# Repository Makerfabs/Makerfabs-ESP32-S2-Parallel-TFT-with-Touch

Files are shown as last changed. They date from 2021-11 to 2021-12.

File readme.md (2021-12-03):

# Makerfabs ESP32-S2 Parallel TFT with Touch

```c++
/*
Version:		V1.0
Author:			Vincent
Create Date:	2021/11/22
Note:
	
*/
```
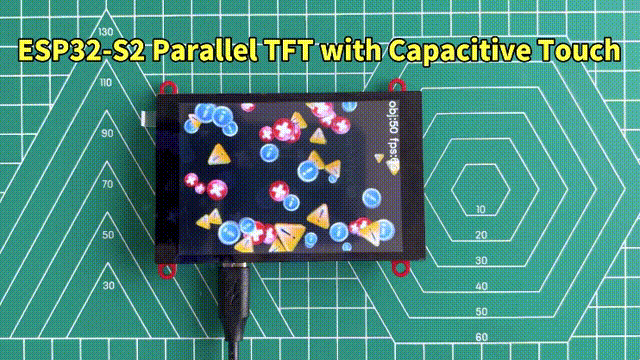
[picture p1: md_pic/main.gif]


[toc]

# Makerfabs

[Makerfabs home page](https://www.makerfabs.com/)

[Makerfabs Wiki](https://makerfabs.com/wiki/index.php?title=Main_Page)

# Makerfabs ESP32-S2 Parallel TFT with Touch
## Intruduce

Product Link ：[esp32-s2-parallel-tft-with-touch-3-5-ili9488](https://www.makerfabs.com/esp32-s2-parallel-tft-with-touch-3-5-ili9488.html) 

Wiki Link : [ESP32-S2 Parallel TFT with Touch(3.5'')](https://www.makerfabs.com/wiki/index.php?title=ESP32-S2_Parallel_TFT_with_Touch(3.5%27%27)) 

The 3.5" 320x480 TFT LCD driver is ILI9488, it uses 16bits parallel line for communication with ESP32-S2, the main clock could be up to 20MHz, make the display smooth enough for videos; You can freely use some of Mabee pins(A I2c and a IOs) with the breakout connectors, to connect the ESP32-S2 display with sensors/ actuators, suitable for IoT applications.

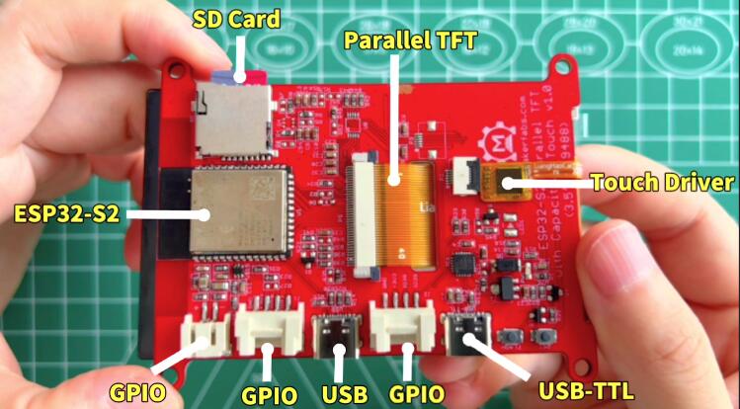
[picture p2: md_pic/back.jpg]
back


## Feature

- Integrated ESP32-S2 with 2.4G WiFi
- Wi-Fi Protocols: 802.11b/g/n(802.11n up to 150Mbps),A-MPDU and A-MSDU aggregation and 0.4us guard interval support
- Wi-Fi Frequency range: 2.402GHz - 2.483Ghz
- Arduino Compatible: You can play it with Arduino IDE
- LCD 3.5 inch Amorphous-TFT-LCD (Thin Film Transistor Liquid Crystal Display) for mobile-phone or handy electrical equipment
- LCD Driver: ILI9488(16bits parallel line)
- LCD Resolution: 320*480
- FT6236 Series ICs are single-chip capacitive touch panel controller IC with a built-in 16 bit enhanced Micro-controller unit (MCU)
- NS2009: A 4-wire resistive touch screen control circuit with I2C interface, which contains A 12-bit resolution A/D converter
- Power supply: 5V, Type-C USB
- Micro SD card slot on the board
- Dual USB Type-C: one for native USB and one for USB-to-UART
- Two Mabee interfaces
- Board size: 66mm * 85mm

# Code Explain

## Complier Option

- Install board : ESP32 .
- Install library : LovyanGFX library. 
- Edit the code based on the touch screen. If you use resistive screen, choice NS2009_TOUCH. If you use capacitive screen, choice FT6236_TOUCH. 
- Use type-c use cable connect USB-TTL to PC.
- Upload codes, select "ESP32-S2 DEV Module" and "UART0"

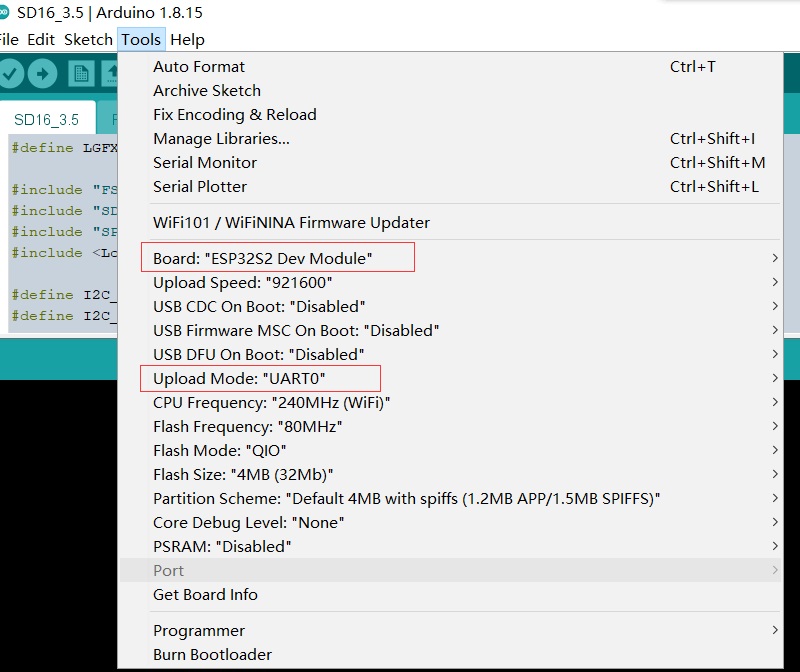
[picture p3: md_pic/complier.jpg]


## Firmware

### SD16_3.5

Factory firmware. First run the boot self-test to check the hardware. Press down the middle of the touch screen as prompted to display a LOGO picture on the SD card. Finally, print the touch coordinates in the serial port.

## Example

### Simple Test

Three frame rate tests and SD card read and write tests.

- FillScreen

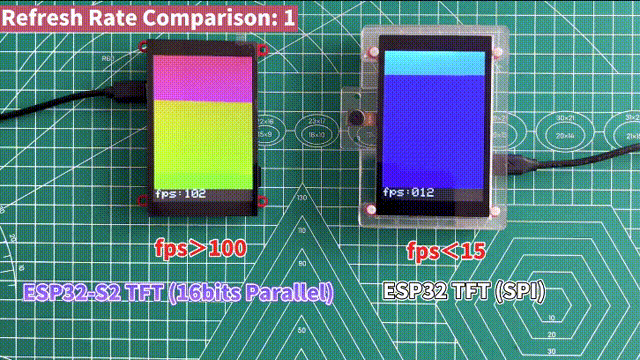
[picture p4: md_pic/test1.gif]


- Graph

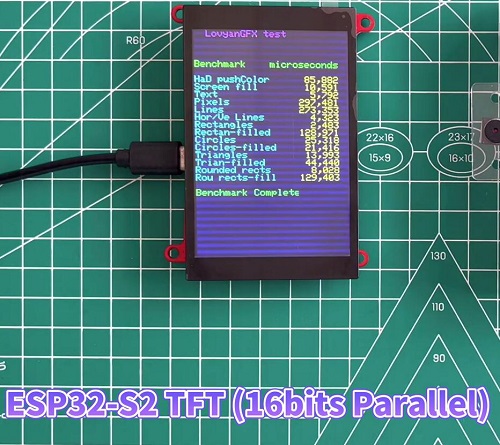
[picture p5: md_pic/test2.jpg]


- Touch

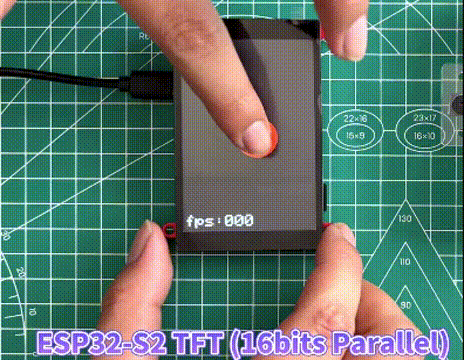
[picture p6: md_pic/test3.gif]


- PWM_backlight

Use pwm control screen back light.

### Display Demo

The display of 5 display effects is modified from Lovyan's example. There are also two homemade demonstration videos: ultrasonic ranging and line charts.

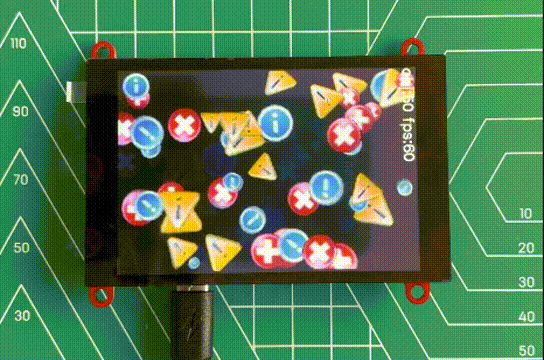
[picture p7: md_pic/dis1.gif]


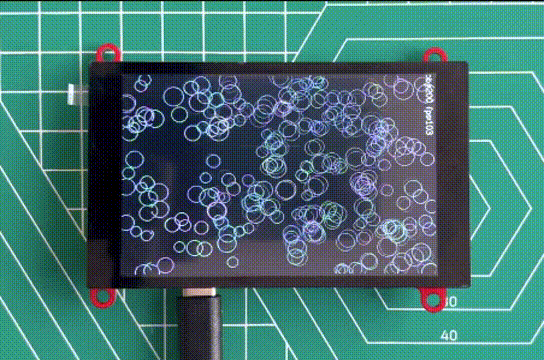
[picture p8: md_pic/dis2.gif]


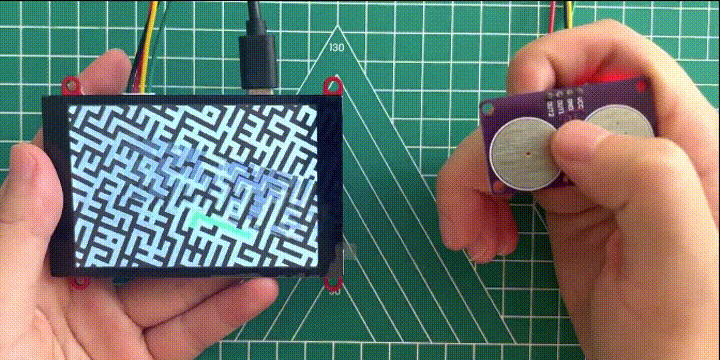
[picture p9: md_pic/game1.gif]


### Wifi Img

Receive TXT and BMP files over WIFI and display them on the screen.

Added a WiFi bulletin board app. You can upload and browse files in the SD card through the web page. And the latest uploaded BMP or TXT display on the 3.5-inch screen.

- Library Install：[esp32-micro-sdcard](https://github.com/nhatuan84/esp32-micro-sdcard) and [esp32-webserver](https://github.com/nhatuan84/esp32-webserver)
- Upload .\example\wifi_img_16\wifi_img_16.ino
- Insert the SD card and power on.
- Enter the IP address on the screen in your browser.

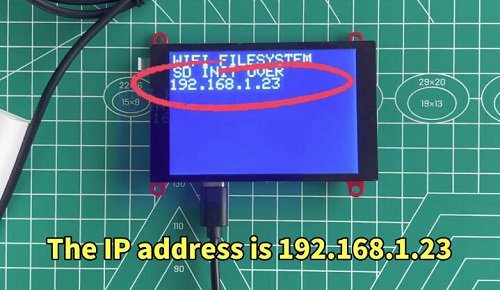
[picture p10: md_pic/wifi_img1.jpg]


- Select TXT or BMP to be uploaded. BMP must be 480 x 320 pixels, 24 bits.

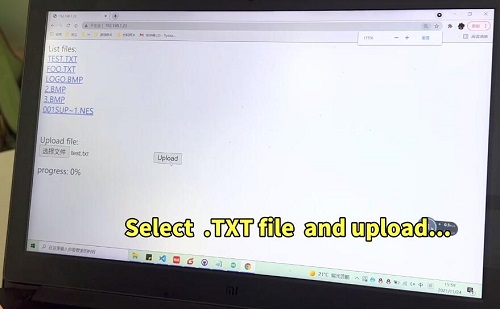
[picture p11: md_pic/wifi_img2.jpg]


- Upload.
- Wait seconds, the content is displayed on the screen.

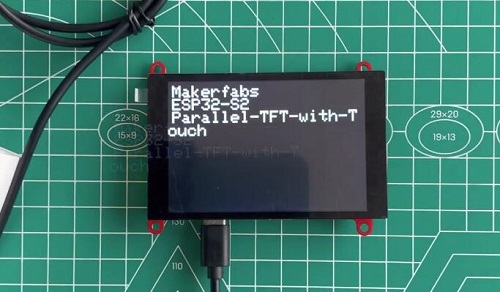
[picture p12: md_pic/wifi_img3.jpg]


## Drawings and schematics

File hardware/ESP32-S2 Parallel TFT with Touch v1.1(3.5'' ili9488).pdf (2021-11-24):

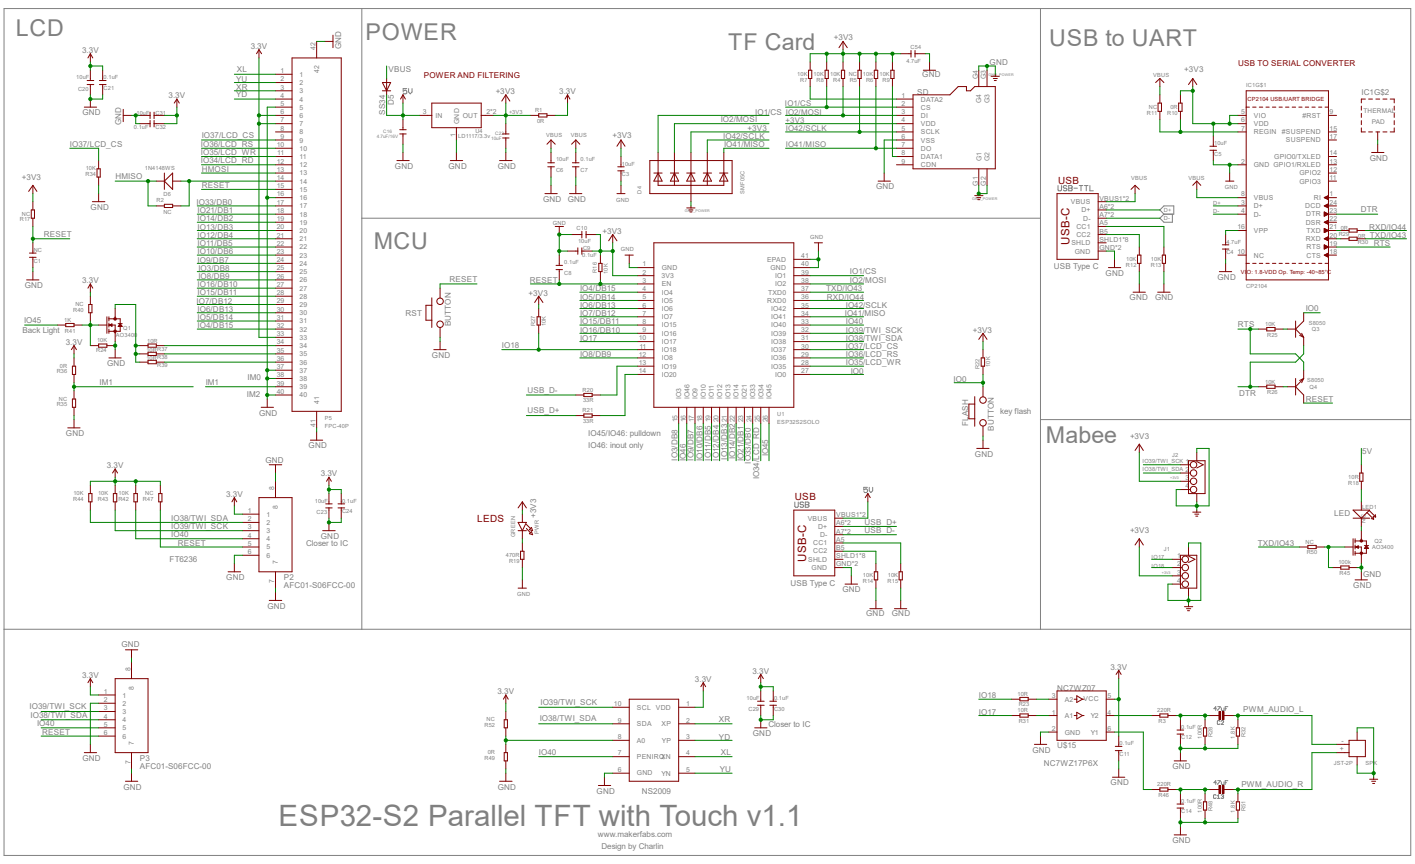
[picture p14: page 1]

USB TO SERIAL CONVERTER

VIO: 1.8-VDD Op. Temp: -40~85°C USB⁻C USB⁻C

IO39/TWI_SCK 3
IO40 4

ESP32-S2 Parallel TFT with Touch v1.1

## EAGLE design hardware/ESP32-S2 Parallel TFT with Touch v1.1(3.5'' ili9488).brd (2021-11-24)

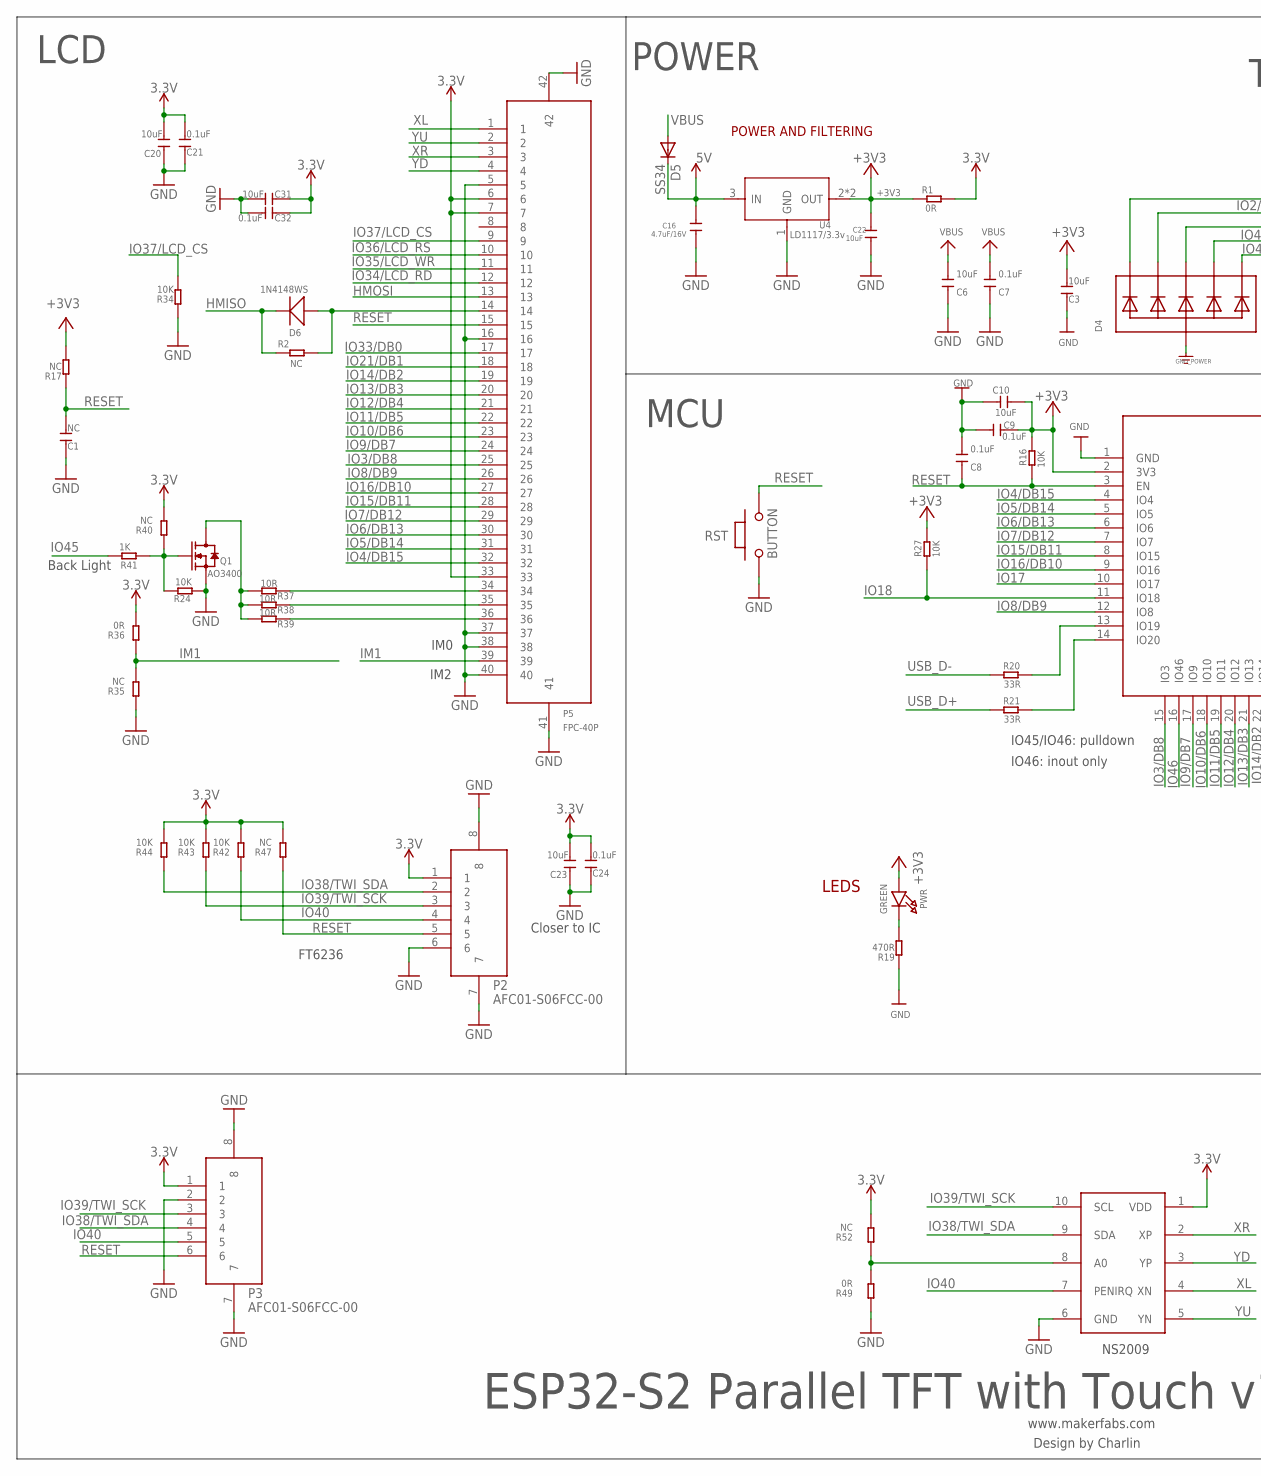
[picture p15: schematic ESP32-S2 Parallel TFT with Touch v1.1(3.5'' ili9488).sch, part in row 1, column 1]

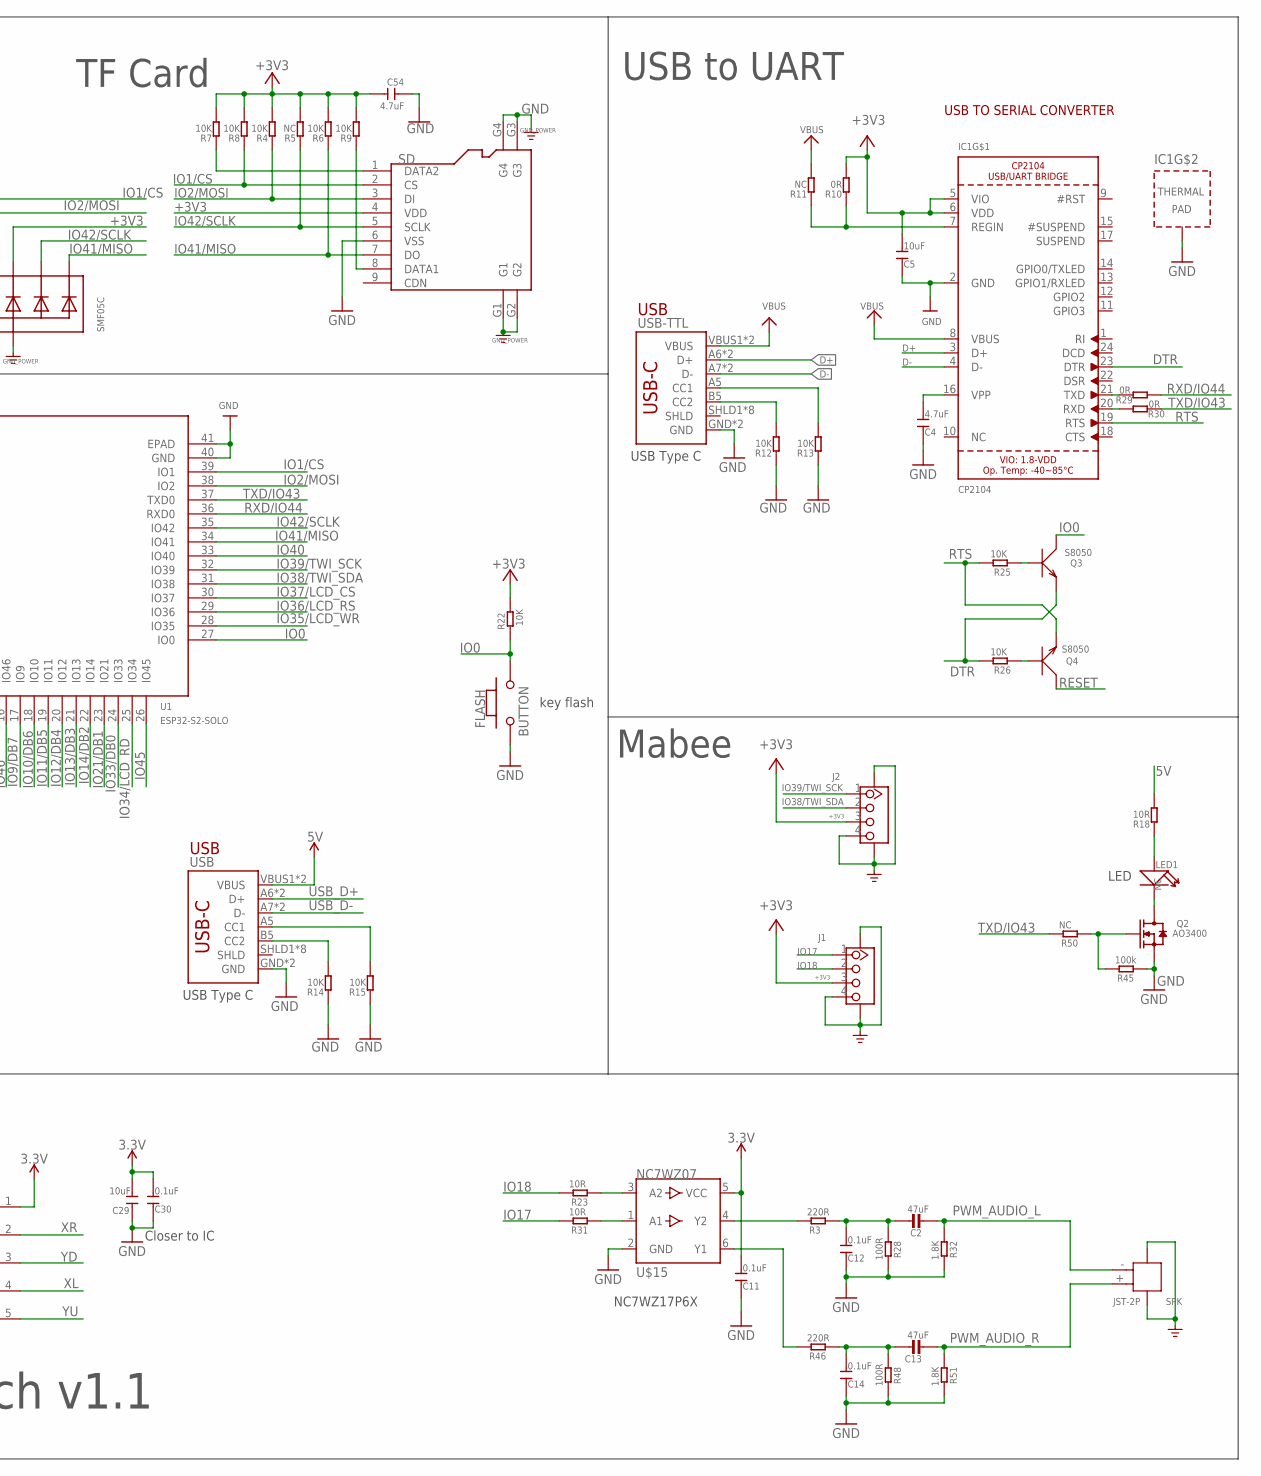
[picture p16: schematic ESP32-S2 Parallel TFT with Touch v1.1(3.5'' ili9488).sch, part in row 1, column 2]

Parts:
C1: NC; DISCRETE_C0603
C2, C13: 47uF; MICROBUILDER_0805
C3, C5, C6, C10, C20, C23, C29, C31: 10uF; DISCRETE_C0603
C4, C54: 4.7uF; DISCRETE_C0603
C7, C8, C9, C11, C12, C14, C21, C24, C30, C32: 0.1uF; DISCRETE_C0603
C16: 4.7uF/16V; 0603
C22: 10uF; 0603
D4: SMF05C; SOT363
D5: SS34; DO-214AC
D6: 1N4148WS; SOD323
FLASH: BUTTON; 157SW
IC1: CP2104; QFN24_4MM_SMSC
J1, J2: GROVE-CONNECTOR-SMD'90D'; HW4-SMD-2.0-90D
LED1: NC; DISCRETE_LED-3528
P2, P3: AFC01-S06FCC-00; SMD8-50P-740L535W
P5: FPC-40P; SMD42-50P-2560L490W
PWR: GREEN; CHIPLED_0805_NOOUTLINE
Q1, Q2: AO3400; SOT23@1
Q3, Q4: S8050; SOT23
R1, R29, R30: 0R; R0603
R2, R50: NC; R0603
R3, R46: 220R; R0603
R4, R6, R7, R8, R9, R12, R13, R14, R15, R24, R34, R42, R43, R44: 10K; DISCRETE_R0603
R5, R11, R17, R35, R40, R47, R52: NC; DISCRETE_R0603
R10, R36, R49: 0R; DISCRETE_R0603
R16, R22, R25, R26, R27: 10K; R0603
R18, R37, R38, R39: 10R; DISCRETE_R0603
R19: 470R; DISCRETE_R0603
R20, R21: 33R; R0603
R23, R31: 10R; R0603
R28, R48: 100R; R0603
R32, R51: 1.8K; R0603
R41: 1K; DISCRETE_R0603
R45: 100k; R0603
RST: BUTTON; 157SW
SD: HOLDER-MICROSD-9P; 9P-SMD-W/-RING
SPK: JST-2P; HW2-SMD-2.0-90D
U1: ESP32­S2­SOLO; ESP32-­S2-­SOLO
U4: LD1117/3.3v; SOT89
U8: NS2009; MSOP10
U$15: NC7WZ07; SC70-6
USB: USB_C5; USB-C-16P-5
USB-TTL: USB_C5; USB-C-16P-5

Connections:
3.3V: C11.2, C20.2, C21.2, C23.2, C24.2, C29.2, C30.2, C31.1, C32.1, P2.1, P3.1, P5.6, P5.7, P5.33, R1.2, R36.2, R40.2, R42.2, R43.2, R44.2, R47.2, R52.2, U8.1 (VDD), U$15.5 (VCC)
5V: C16.1, D5.C, R18.2, U4.3 (IN), USB.VBUS1 (VBUS), USB.VBUS2 (VBUS)
+3V3: C3.2, C5.2, C9.1, C10.1, C22.1, C54.2, D4.4 (C3), IC1.5 (VIO), IC1.6 (VDD), J1.3, J2.3, PWR.A, R1.1, R4.2, R5.2, R6.2, R7.2, R8.2, R9.2, R10.2, R16.2, R17.2, R22.2, R27.2, SD.4 (VDD), U1.2 (3V3), U4.2 (OUT), U4.4 (OUT)
D+: IC1.3 (D+), USB-TTL.A6 (D+), USB-TTL.B6 (D+)
D-: IC1.4 (D-), USB-TTL.A7 (D-), USB-TTL.B7 (D-)
DTR: IC1.23 (DTR), Q3.2 (E), R26.2
GND: C1.1, C3.1, C4.1, C5.1, C6.1, C7.1, C8.2, C9.2, C10.2, C11.1, C12.1, C14.1, C16.2, C20.1, C21.1, C22.2, C23.1, C24.1, C29.1, C30.1, C31.2, C32.2, C54.1, D4.2 (A), FLASH.1, IC1.2 (GND), IC1.THERM (TP), J1.4, J1.SS1, J1.SS2, J2.4, J2.SS1, J2.SS2, P2.6, P2.7, P2.8, P3.2, P3.7, P3.8, P5.5, P5.16, P5.37, P5.38, P5.40, P5.41, P5.42, Q1.2 (S), Q2.2 (S), R12.1, R13.1, R14.1, R15.1, R19.1, R24.1, R28.2, R32.2, R34.1, R35.1, R45.1, R48.2, R49.1, R51.2, RST.1, SD.6 (VSS), SD.G1, SD.G2, SD.G3, SD.G4, SPK.3, SPK.4, U1.1 (GND), U1.40 (GND), U1.41 (EPAD), U4.1 (GND), U8.6 (GND), U$15.2 (GND), USB.GND, USB.GND2 (GND), USB-TTL.GND, USB-TTL.GND2 (GND)
HMISO: D6.-, R2.1
HMOSI: P5.13
IM1: P5.39, R35.2, R36.1
IO0: FLASH.2, Q3.3 (C), R22.1, U1.27 (IO0)
IO1/CS: D4.1 (C1), R8.1, SD.2 (CS), U1.39 (IO1)
IO2/MOSI: D4.3 (C2), R4.1, SD.3 (DI), U1.38 (IO2)
IO3/DB8: P5.25, U1.15 (IO3)
IO4/DB15: P5.32, U1.4 (IO4)
IO5/DB14: P5.31, U1.5 (IO5)
IO6/DB13: P5.30, U1.6 (IO6)
IO7/DB12: P5.29, U1.7 (IO7)
IO8/DB9: P5.26, U1.12 (IO8)
IO9/DB7: P5.24, U1.17 (IO9)
IO10/DB6: P5.23, U1.18 (IO10)
IO11/DB5: P5.22, U1.19 (IO11)
IO12/DB4: P5.21, U1.20 (IO12)
IO13/DB3: P5.20, U1.21 (IO13)
IO14/DB2: P5.19, U1.22 (IO14)
IO15/DB11: P5.28, U1.8 (IO15)
IO16/DB10: P5.27, U1.9 (IO16)
IO17: J1.1, R31.2, U1.10 (IO17)
IO18: J1.2, R23.2, R27.1, U1.11 (IO18)
IO21/DB1: P5.18, U1.23 (IO21)
IO33/DB0: P5.17, U1.24 (IO33)
IO34/LCD_RD: P5.12, U1.25 (IO34)
IO35/LCD_WR: P5.11, U1.28 (IO35)
IO36/LCD_RS: P5.10, U1.29 (IO36)
IO37/LCD_CS: P5.9, R34.2, U1.30 (IO37)
IO38/TWI_SDA: J2.2, P2.2, P3.4, R44.1, U1.31 (IO38), U8.9 (SDA)
IO39/TWI_SCK: J2.1, P2.3, P3.3, R43.1, U1.32 (IO39), U8.10 (SCL)
IO40: P2.4, P3.5, R42.1, U1.33 (IO40), U8.7 (PENIRQ)
IO41/MISO: D4.6 (C5), R6.1, SD.7 (DO), U1.34 (IO41)
IO42/SCLK: D4.5 (C4), R5.1, SD.5 (SCLK), U1.35 (IO42)
IO45: R41.2, U1.26 (IO45)
IO46: U1.16 (IO46)
unnamed: C4.2, IC1.16 (VPP)
unnamed: Q4.1 (B), R26.1
unnamed: Q3.1 (B), R25.1
unnamed: D6.+, P5.14, R2.2
unnamed: Q2.1 (G), R45.2, R50.1
unnamed: R15.2, USB.A5 (CC1)
unnamed: PWR.C, R19.2
unnamed: LED1.1 (+), R18.1
unnamed: LED1.2 (-), Q2.3 (D)
unnamed: R13.2, USB-TTL.A5 (CC1)
unnamed: R12.2, USB-TTL.B5 (CC2)
unnamed: IC1.7 (REGIN), R10.1, R11.1
unnamed: R3.2, U$15.4 (Y2)
unnamed: R14.2, USB.B5 (CC2)
unnamed: R20.2, U1.13 (IO19)
unnamed: R21.2, U1.14 (IO20)
unnamed: C2.1, C12.2, R3.1, R28.1
unnamed: IC1.21 (TXD), R29.2
unnamed: IC1.20 (RXD), R30.2
unnamed: P5.34, R37.1
unnamed: P5.35, R38.1
unnamed: P5.36, R39.1
unnamed: Q1.1 (G), R24.2, R40.1, R41.1
unnamed: Q1.3 (D), R37.2, R38.2, R39.2
unnamed: R49.2, R52.1, U8.8 (A0)
unnamed: R46.2, U$15.6 (Y1)
unnamed: R23.1, U$15.3 (A2)
unnamed: R31.1, U$15.1 (A1)
unnamed: C13.1, C14.2, R46.1, R48.1
unnamed: R7.1, SD.1 (DATA2)
unnamed: R9.1, SD.8 (DATA1)
PWM_AUDIO_L: C2.2, R32.1, SPK.- (2)
PWM_AUDIO_R: C13.2, R51.1, SPK.+ (1)
RESET: C1.2, C8.1, P2.5, P3.6, P5.15, Q4.3 (C), R16.1, R17.1, R47.1, RST.2, U1.3 (EN)
RTS: IC1.19 (RTS), Q4.2 (E), R25.2
RXD/IO44: R29.1, U1.36 (RXD0)
TXD/IO43: R30.1, R50.2, U1.37 (TXD0)
USB_D+: R21.1, USB.A6 (D+), USB.B6 (D+)
USB_D-: R20.1, USB.A7 (D-), USB.B7 (D-)
VBUS: C6.2, C7.2, D5.A, IC1.8 (VBUS), R11.2, USB-TTL.VBUS1 (VBUS), USB-TTL.VBUS2 (VBUS)
XL: P5.1, U8.4 (XN)
XR: P5.3, U8.2 (XP)
YD: P5.4, U8.3 (YP)
YU: P5.2, U8.5 (YN)

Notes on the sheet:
www.makerfabs.com
Design by Charlin
USB
LEDS
POWER AND FILTERING
USB TO SERIAL CONVERTER
key flash
ESP32-S2 Parallel TFT with Touch v1.1
POWER
USB to UART
USB Type C
TF Card
LED
NS2009
FT6236
Closer to IC
Back Light
IM0
IM2
IO45/IO46: pulldown
IO46: inout only
NC7WZ17P6X
Mabee
LCD
MCU

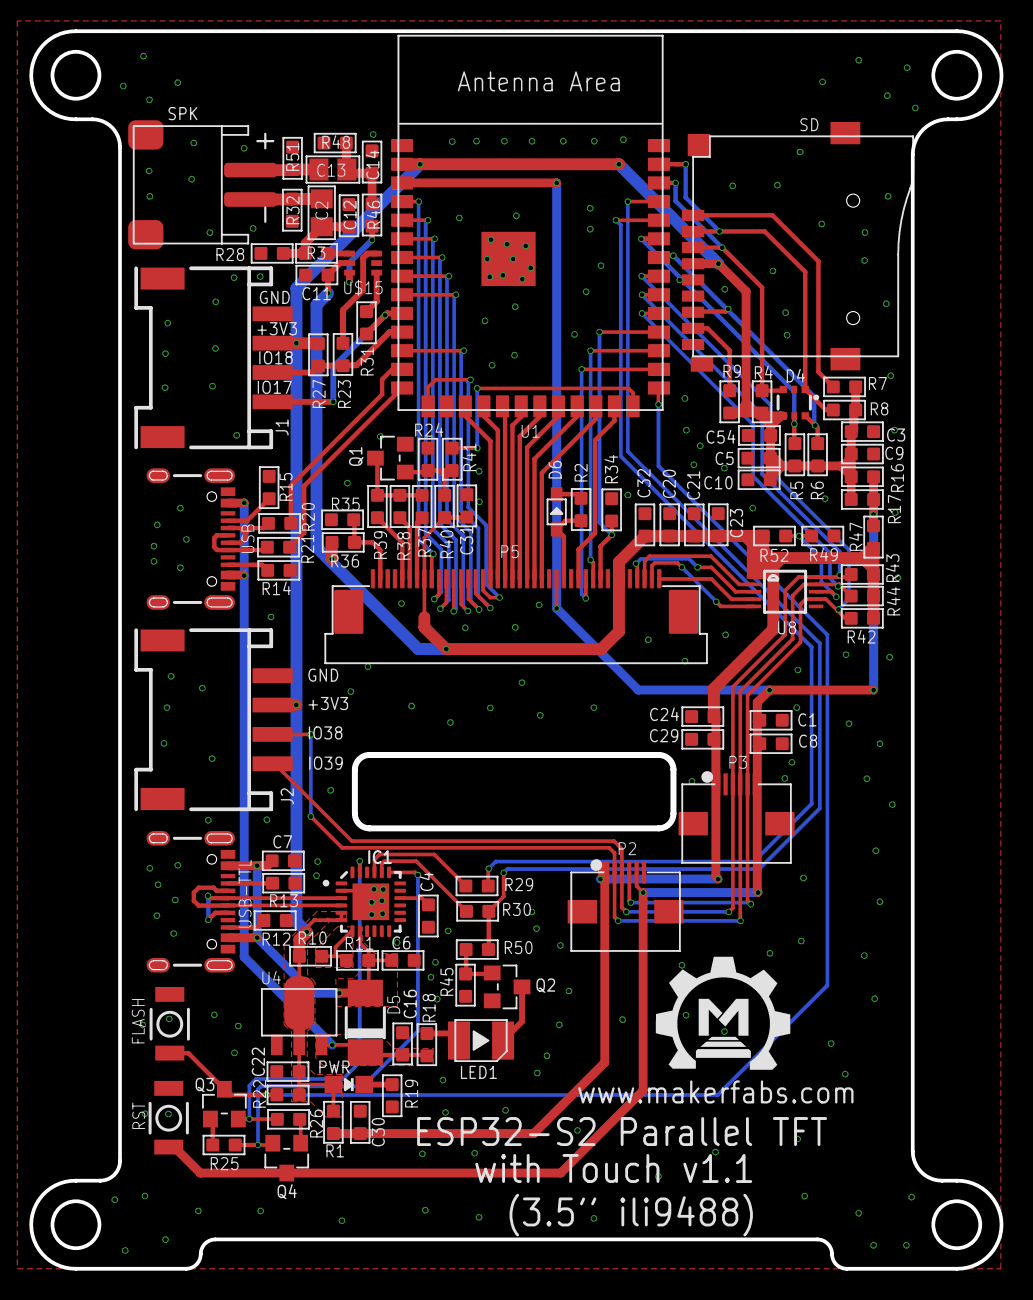
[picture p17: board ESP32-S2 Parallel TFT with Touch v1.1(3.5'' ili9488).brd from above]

Board: 2 copper layers, 66.1 x 84.3 mm, 102 parts (0 on the bottom side), 84 nets.

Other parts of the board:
U$1: MAKERFABS_0.3

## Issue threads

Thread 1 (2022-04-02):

ESP32 Version

phpbbireland, 2022-04-02:
Everything was down to wrong versions.
Trying to compile wrong example with wrong board.
I thought I ordered 1 SPI and 1 Parallel both being the S3 variants but one was S2, confusion ensued...
Apologies...

phpbbireland, 2022-04-02:
Examples won't compile with ESP32 beta 2.0.3-RC1, 2.0.2 works perfectly...

phpbbireland, 2023-08-23:
All issues solved... need to buy an ESP32-S3 Parallel version ;)

Closed 2023-08-23.

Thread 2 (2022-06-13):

Connecting SPI peripheral (eg LoRa module)

spleenware, 2022-06-13:
Is it possible to connect an external SPI module?
I can see the 2 grove connectors,  one for I2C, the other just 2 GPIO's (18, and 19  I think). Just wondering about SPI, though.

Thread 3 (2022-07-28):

Cap touch panel calibration error?

nikthefix, 2022-07-28:
Hi, I have 2 of these boards. I've noticed that the cap touch coords do not perfectly align with the display in the demo code or any of my user code. To correctly align consistently requires a bias coord value of +/-20 in both axes at the extremes. Alignment is perfect in the center at 240,160. Any ideas why? I can correct it using the 'map' function to produce a proportional scaling . Is it possible the touch glass component is not correctly sized to the ili9488 module?

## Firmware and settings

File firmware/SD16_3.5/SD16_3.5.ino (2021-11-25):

#define LGFX_USE_V1

#include "FS.h"
#include "SD.h"
#include "SPI.h"
#include <LovyanGFX.hpp>

#define I2C_SCL 39
#define I2C_SDA 38

//#define NS2009_TOUCH  //Resistive screen driver
#define FT6236_TOUCH //Capacitive screen driver

#ifdef NS2009_TOUCH
#include "NS2009.h"
const int i2c_touch_addr = NS2009_ADDR;
#define get_pos ns2009_pos
#endif

#ifdef FT6236_TOUCH
#include "FT6236.h"
const int i2c_touch_addr = TOUCH_I2C_ADD;
#define get_pos ft6236_pos
#endif

#define SPI_MOSI 2 //1
#define SPI_MISO 41
#define SPI_SCK 42
#define SD_CS 1 //2

#define LCD_CS 37
#define LCD_BLK 45

class LGFX : public lgfx::LGFX_Device
{
    //lgfx::Panel_ILI9341 _panel_instance;
    lgfx::Panel_ILI9488 _panel_instance;
    lgfx::Bus_Parallel16 _bus_instance; // 8ビットパラレルバスのインスタンス (ESP32のみ)

public:
    // コンストラクタを作成し、ここで各種設定を行います。
    // クラス名を変更した場合はコンストラクタも同じ名前を指定してください。
    LGFX(void)
    {
        {                                      // バス制御の設定を行います。
            auto cfg = _bus_instance.config(); // バス設定用の構造体を取得します。

            // 16位设置
            cfg.i2s_port = I2S_NUM_0;  // 使用するI2Sポートを選択 (0 or 1) (ESP32のI2S LCDモードを使用します)
            cfg.freq_write = 16000000; // 送信クロック (最大20MHz, 80MHzを整数で割った値に丸められます)
            cfg.pin_wr = 35;           // WR を接続しているピン番号
            cfg.pin_rd = 34;           // RD を接続しているピン番号
            cfg.pin_rs = 36;           // RS(D/C)を接続しているピン番号

            cfg.pin_d0 = 33;
            cfg.pin_d1 = 21;
            cfg.pin_d2 = 14;
            cfg.pin_d3 = 13;
            cfg.pin_d4 = 12;
            cfg.pin_d5 = 11;
            cfg.pin_d6 = 10;
            cfg.pin_d7 = 9;
            cfg.pin_d8 = 3;
            cfg.pin_d9 = 8;
            cfg.pin_d10 = 16;
            cfg.pin_d11 = 15;
            cfg.pin_d12 = 7;
            cfg.pin_d13 = 6;
            cfg.pin_d14 = 5;
            cfg.pin_d15 = 4;

            _bus_instance.config(cfg);              // 設定値をバスに反映します。
            _panel_instance.setBus(&_bus_instance); // バスをパネルにセットします。
        }

        {                                        // 表示パネル制御の設定を行います。
            auto cfg = _panel_instance.config(); // 表示パネル設定用の構造体を取得します。

            cfg.pin_cs = -1;   // CS要拉低
            cfg.pin_rst = -1;  // RST和开发板RST相连
            cfg.pin_busy = -1; // BUSYが接続されているピン番号 (-1 = disable)

            // ※ 以下の設定値はパネル毎に一般的な初期値が設定されていますので、不明な項目はコメントアウトして試してみてください。

            cfg.memory_width = 320;   // ドライバICがサポートしている最大の幅
            cfg.memory_height = 480;  // ドライバICがサポートしている最大の高さ
            cfg.panel_width = 320;    // 実際に表示可能な幅
            cfg.panel_height = 480;   // 実際に表示可能な高さ
            cfg.offset_x = 0;         // パネルのX方向オフセット量
            cfg.offset_y = 0;         // パネルのY方向オフセット量
            cfg.offset_rotation = 0;  // 回転方向の値のオフセット 0~7 (4~7は上下反転)
            cfg.dummy_read_pixel = 8; // ピクセル読出し前のダミーリードのビット数
            cfg.dummy_read_bits = 1;  // ピクセル以外のデータ読出し前のダミーリードのビット数
            cfg.readable = true;      // データ読出しが可能な場合 trueに設定
            cfg.invert = false;       // パネルの明暗が反転してしまう場合 trueに設定
            cfg.rgb_order = false;    // パネルの赤と青が入れ替わってしまう場合 trueに設定
            cfg.dlen_16bit = true;    // データ長を16bit単位で送信するパネルの場合 trueに設定
            cfg.bus_shared = true;    // SDカードとバスを共有している場合 trueに設定(drawJpgFile等でバス制御を行います)

            _panel_instance.config(cfg);
        }

        setPanel(&_panel_instance); // 使用するパネルをセットします。
    }
};

LGFX lcd;
int pos[2] = {0, 0};
int err_code = 0;

void setup()
{
    pinMode(LCD_CS, OUTPUT);
    pinMode(LCD_BLK, OUTPUT);

    digitalWrite(LCD_CS, LOW);
    digitalWrite(LCD_BLK, HIGH);

    Serial.begin(115200);

    lcd.init();
    lcd.fillScreen(TFT_BLUE);
    lcd.setTextColor(TFT_YELLOW);
    lcd.setTextSize(2);
    lcd.setCursor(0, 0);
    lcd.print("Makerfabs ESP32-S2");
    lcd.setCursor(0, 16);
    lcd.print("Parallel TFT with Touch");

    SPI.begin(SPI_SCK, SPI_MISO, SPI_MOSI);

    lcd.setCursor(0, 32);
    if (SD_init())
    {
        lcd.print("ERROR:   SD");
        err_code += 1;
    }
    else
        lcd.print("SD INIT OVER");

    //I2C init
    Wire.begin(I2C_SDA, I2C_SCL);
    byte error, address;

    Wire.beginTransmission(i2c_touch_addr);
    error = Wire.endTransmission();

    lcd.setCursor(0, 48);
    if (error == 0)
    {
        Serial.print("I2C device found at address 0x");
        Serial.print(i2c_touch_addr, HEX);
        Serial.println("  !");
        lcd.print("TOUCH INIT OVER");
    }
    else
    {
        Serial.print("Unknown error at address 0x");
        Serial.println(i2c_touch_addr, HEX);
        lcd.print("ERROR:   TOUCH");
        err_code += 1;
    }

    lcd.setCursor(0, 64);
    if (err_code)
    {

        lcd.print("SOMETHING WRONG");
        while (1)
            ;
    }
    else
        lcd.print("ALL SUCCESS");

    lcd.setRotation(1);

    int rect_length = 40;

    lcd.fillRect(240 - rect_length, 160 - rect_length, rect_length * 2, rect_length * 2, TFT_RED);

    lcd.setCursor(100, 10);
    lcd.print(F("TOUCH RED RECT"));

    while (1)
    {
        if (get_pos(pos))
        {
            if (pos[0] < 160 + rect_length && pos[0] > 160 - rect_length && pos[1] < 240 + rect_length && pos[1] > 240 - rect_length)
                break;
        }
        delay(10);
        Serial.println("No touch");
    }

    lcd.setRotation(3);
    print_img(SD, "/logo.bmp", 480, 320);
}

void loop()
{
    if (get_pos(pos))
    {
        Serial.println((String)"x=" + pos[0] + ",y=" + pos[1]);
    }

    delay(100);
}

int SD_init()
{

    if (!SD.begin(SD_CS))
    {
        Serial.println("Card Mount Failed");
        return 1;
    }
    uint8_t cardType = SD.cardType();

    if (cardType == CARD_NONE)
    {
        Serial.println("No SD card attached");
        return 1;
    }

    Serial.print("SD Card Type: ");
    if (cardType == CARD_MMC)
    {
        Serial.println("MMC");
    }
    else if (cardType == CARD_SD)
    {
        Serial.println("SDSC");
    }
    else if (cardType == CARD_SDHC)
    {
        Serial.println("SDHC");
    }
    else
    {
        Serial.println("UNKNOWN");
    }

    uint64_t cardSize = SD.cardSize() / (1024 * 1024);
    Serial.printf("SD Card Size: %lluMB\n", cardSize);
    listDir(SD, "/", 2);

    Serial.println("SD init over.");
    return 0;
}

void listDir(fs::FS &fs, const char *dirname, uint8_t levels)
{
    Serial.printf("Listing directory: %s\n", dirname);

    File root = fs.open(dirname);
    if (!root)
    {
        Serial.println("Failed to open directory");
        return;
    }
    if (!root.isDirectory())
    {
        Serial.println("Not a directory");
        return;
    }

    File file = root.openNextFile();
    while (file)
    {
        if (file.isDirectory())
        {
            Serial.print("  DIR : ");
            Serial.println(file.name());
            if (levels)
            {
                listDir(fs, file.name(), levels - 1);
            }
        }
        else
        {
            Serial.print("  FILE: ");
            Serial.print(file.name());
            Serial.print("  SIZE: ");
            Serial.println(file.size());
        }
        file = root.openNextFile();
    }
}

void readFile(fs::FS &fs, const char *path)
{
    Serial.printf("Reading file: %s\n", path);

    File file = fs.open(path);
    if (!file)
    {
        Serial.println("Failed to open file for reading");
        return;
    }

    Serial.print("Read from file: ");
    while (file.available())
    {
        Serial.write(file.read());
    }
    file.close();
}

void writeFile(fs::FS &fs, const char *path, const char *message)
{
    Serial.printf("Writing file: %s\n", path);

    File file = fs.open(path, FILE_WRITE);
    if (!file)
    {
        Serial.println("Failed to open file for writing");
        return;
    }
    if (file.print(message))
    {
        Serial.println("File written");
    }
    else
    {
        Serial.println("Write failed");
    }
    file.close();
}

void appendFile(fs::FS &fs, const char *path, const char *message)
{
    Serial.printf("Appending to file: %s\n", path);

    File file = fs.open(path, FILE_APPEND);
    if (!file)
    {
        Serial.println("Failed to open file for appending");
        return;
    }
    if (file.print(message))
    {
        Serial.println("Message appended");
    }
    else
    {
        Serial.println("Append failed");
    }
    file.close();
}

//Display image from file
int print_img(fs::FS &fs, String filename, int x, int y)
{
    File f = fs.open(filename, "r");
    if (!f)
    {
        Serial.println("Failed to open file for reading");
        f.close();
        return 0;
    }

    f.seek(54);
    int X = x;
    int Y = y;
    uint8_t RGB[3 * X];
    for (int row = 0; row < Y; row++)
    {
        f.seek(54 + 3 * X * row);
        f.read(RGB, 3 * X);
        lcd.pushImage(0, row, X, 1, (lgfx::rgb888_t *)RGB);
    }

    f.close();
    return 0;
}

//Display image from file
//BMP is 32 bit...
int print_img_small(fs::FS &fs, String filename, int x, int y, int w, int h)
{
    File f = fs.open(filename, "r");
    if (!f)
    {
        Serial.println("Failed to open file for reading");
        f.close();
        return 0;
    }

    f.seek(54);
    int X = w;
    int Y = h;
    uint8_t RGB[3 * X];
    uint8_t RGBA[4 * X];
    for (int row = 0; row < Y; row++)
    {
        f.seek(54 + 4 * X * row);
        f.read(RGBA, 4 * X);

        for (int i = 0; i < X; i++)
        {
            RGB[3 * i] = RGBA[4 * X - 4 * i - 4];
            RGB[3 * i + 1] = RGBA[4 * X - 4 * i - 3];
            RGB[3 * i + 2] = RGBA[4 * X - 4 * i - 2];
        }
        lcd.pushImage(x, y + row, X, 1, (lgfx::rgb888_t *)RGB);
    }

    f.close();
    return 0;
}

//transform touch screen pos
void pos_rotation(int pos[2], int rotation)
{
    if (pos[0] == -1)
        return;
    if (rotation == 0)
    {
        return;
    }
    if (rotation == 3)
    {
        int tempx = 480 - pos[1];
        int tempy = pos[0];
        pos[0] = tempx;
        pos[1] = tempy;
    }
}

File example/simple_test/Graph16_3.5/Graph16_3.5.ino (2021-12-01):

//Graph test
#define LGFX_USE_V1

#include <LovyanGFX.hpp>
#include <vector>

#define LCD_CS 37
#define LCD_BLK 45

#define LINE_COUNT 6

class LGFX : public lgfx::LGFX_Device
{
  //lgfx::Panel_ILI9341 _panel_instance;
  lgfx::Panel_ILI9488 _panel_instance;
  lgfx::Bus_Parallel16 _bus_instance; // 8ビットパラレルバスのインスタンス (ESP32のみ)

public:
  // コンストラクタを作成し、ここで各種設定を行います。
  // クラス名を変更した場合はコンストラクタも同じ名前を指定してください。
  LGFX(void)
  {
    {                                    // バス制御の設定を行います。
      auto cfg = _bus_instance.config(); // バス設定用の構造体を取得します。

      // 16位设置
      cfg.i2s_port = I2S_NUM_0;  // 使用するI2Sポートを選択 (0 or 1) (ESP32のI2S LCDモードを使用します)
      cfg.freq_write = 16000000; // 送信クロック (最大20MHz, 80MHzを整数で割った値に丸められます)
      cfg.pin_wr = 35;           // WR を接続しているピン番号
      cfg.pin_rd = 34;           // RD を接続しているピン番号
      cfg.pin_rs = 36;           // RS(D/C)を接続しているピン番号

      cfg.pin_d0 = 33;
      cfg.pin_d1 = 21;
      cfg.pin_d2 = 14;
      cfg.pin_d3 = 13;
      cfg.pin_d4 = 12;
      cfg.pin_d5 = 11;
      cfg.pin_d6 = 10;
      cfg.pin_d7 = 9;
      cfg.pin_d8 = 3;
      cfg.pin_d9 = 8;
      cfg.pin_d10 = 16;
      cfg.pin_d11 = 15;
      cfg.pin_d12 = 7;
      cfg.pin_d13 = 6;
      cfg.pin_d14 = 5;
      cfg.pin_d15 = 4;

      _bus_instance.config(cfg);              // 設定値をバスに反映します。
      _panel_instance.setBus(&_bus_instance); // バスをパネルにセットします。
    }

    {                                      // 表示パネル制御の設定を行います。
      auto cfg = _panel_instance.config(); // 表示パネル設定用の構造体を取得します。

      cfg.pin_cs = -1;   // CS要拉低
      cfg.pin_rst = -1;  // RST和开发板RST相连
      cfg.pin_busy = -1; // BUSYが接続されているピン番号 (-1 = disable)

      // ※ 以下の設定値はパネル毎に一般的な初期値が設定されていますので、不明な項目はコメントアウトして試してみてください。

      cfg.memory_width = 320;   // ドライバICがサポートしている最大の幅
      cfg.memory_height = 480;  // ドライバICがサポートしている最大の高さ
      cfg.panel_width = 320;    // 実際に表示可能な幅
      cfg.panel_height = 480;   // 実際に表示可能な高さ
      cfg.offset_x = 0;         // パネルのX方向オフセット量
      cfg.offset_y = 0;         // パネルのY方向オフセット量
      cfg.offset_rotation = 0;  // 回転方向の値のオフセット 0~7 (4~7は上下反転)
      cfg.dummy_read_pixel = 8; // ピクセル読出し前のダミーリードのビット数
      cfg.dummy_read_bits = 1;  // ピクセル以外のデータ読出し前のダミーリードのビット数
      cfg.readable = true;      // データ読出しが可能な場合 trueに設定
      cfg.invert = false;       // パネルの明暗が反転してしまう場合 trueに設定
      cfg.rgb_order = false;    // パネルの赤と青が入れ替わってしまう場合 trueに設定
      cfg.dlen_16bit = true;    // データ長を16bit単位で送信するパネルの場合 trueに設定
      cfg.bus_shared = true;    // SDカードとバスを共有している場合 trueに設定(drawJpgFile等でバス制御を行います)

      _panel_instance.config(cfg);
    }

    setPanel(&_panel_instance); // 使用するパネルをセットします。
  }
};

static LGFX tft;
// static TFT_eSPI tft;

unsigned long total = 0;
unsigned long tn = 0;
void setup()
{
  pinMode(LCD_CS, OUTPUT);
  pinMode(LCD_BLK, OUTPUT);

  digitalWrite(LCD_CS, LOW);
  digitalWrite(LCD_BLK, HIGH);

  Serial.begin(115200);
  Serial.println("");
  Serial.println("");
  Serial.println("Lovyan's LovyanGFX library Test!");

  tft.init();
  tft.setRotation(0);
  tft.startWrite();
}

void loop(void)
{
  Serial.println(F("Benchmark                Time (microseconds)"));

  uint32_t usecHaD = testHaD();
  Serial.print(F("HaD pushColor            "));
  Serial.println(usecHaD);
  delay(100);

  uint32_t usecFillScreen = testFillScreen();
  Serial.print(F("Screen fill              "));
  Serial.println(usecFillScreen);
  delay(100);

  uint32_t usecText = testText();
  Serial.print(F("Text                     "));
  Serial.println(usecText);
  delay(100);

  uint32_t usecPixels = testPixels();
  Serial.print(F("Pixels                   "));
  Serial.println(usecPixels);
  delay(100);

  uint32_t usecLines = testLines(TFT_BLUE);
  Serial.print(F("Lines                    "));
  Serial.println(usecLines);
  delay(100);

  uint32_t usecFastLines = testFastLines(TFT_RED, TFT_BLUE);
  Serial.print(F("Horiz/Vert Lines         "));
  Serial.println(usecFastLines);
  delay(100);

  uint32_t usecRects = testRects(TFT_GREEN);
  Serial.print(F("Rectangles (outline)     "));
  Serial.println(usecRects);
  delay(100);

  uint32_t usecFilledRects = testFilledRects(TFT_YELLOW, TFT_MAGENTA);
  Serial.print(F("Rectangles (filled)      "));
  Serial.println(usecFilledRects);
  delay(100);

  uint32_t usecFilledCircles = testFilledCircles(10, TFT_MAGENTA);
  Serial.print(F("Circles (filled)         "));
  Serial.println(usecFilledCircles);
  delay(100);

  uint32_t usecCircles = testCircles(10, TFT_WHITE);
  Serial.print(F("Circles (outline)        "));
  Serial.println(usecCircles);
  delay(100);

  uint32_t usecTriangles = testTriangles();
  Serial.print(F("Triangles (outline)      "));
  Serial.println(usecTriangles);
  delay(100);

  uint32_t usecFilledTrangles = testFilledTriangles();
  Serial.print(F("Triangles (filled)       "));
  Serial.println(usecFilledTrangles);
  delay(100);

  uint32_t usecRoundRects = testRoundRects();
  Serial.print(F("Rounded rects (outline)  "));
  Serial.println(usecRoundRects);
  delay(100);

  uint32_t usedFilledRoundRects = testFilledRoundRects();
  Serial.print(F("Rounded rects (filled)   "));
  Serial.println(usedFilledRoundRects);
  delay(100);

  Serial.println(F("Done!"));

  uint16_t c = 4;
  int8_t d = 1;
  for (int32_t i = 0; i < tft.height(); i++)
  {
    tft.drawFastHLine(0, i, tft.width(), c);
    c += d;
    if (c <= 4 || c >= 11)
      d = -d;
  }


  tft.setCursor(0, 0);
  tft.setTextColor(TFT_MAGENTA);
  tft.setTextSize(2);

  tft.println(F("  LovyanGFX test"));

  tft.setTextSize(2);
  tft.setTextColor(TFT_WHITE);
  tft.println(F(""));
  tft.setTextSize(2);
  tft.println(F(""));
  tft.setTextColor(tft.color565(0x80, 0x80, 0x80));

  tft.println(F(""));

  tft.setTextColor(TFT_GREEN);
  tft.println(F("Benchmark    microseconds"));
  tft.println(F(""));
  tft.setTextColor(TFT_YELLOW);

  tft.setTextColor(TFT_CYAN);
  tft.setTextSize(2);
  tft.print(F("HaD pushColor  "));
  tft.setTextColor(TFT_YELLOW);
  tft.setTextSize(2);
  printnice(usecHaD);

  tft.setTextColor(TFT_CYAN);
  tft.setTextSize(2);
  tft.print(F("Screen fill    "));
  tft.setTextColor(TFT_YELLOW);
  tft.setTextSize(2);
  printnice(usecFillScreen);

  tft.setTextColor(TFT_CYAN);
  tft.setTextSize(2);
  tft.print(F("Text           "));
  tft.setTextColor(TFT_YELLOW);
  tft.setTextSize(2);
  printnice(usecText);

  tft.setTextColor(TFT_CYAN);
  tft.setTextSize(2);
  tft.print(F("Pixels         "));
  tft.setTextColor(TFT_YELLOW);
  tft.setTextSize(2);
  printnice(usecPixels);

  tft.setTextColor(TFT_CYAN);
  tft.setTextSize(2);
  tft.print(F("Lines          "));
  tft.setTextColor(TFT_YELLOW);
  tft.setTextSize(2);
  printnice(usecLines);

  tft.setTextColor(TFT_CYAN);
  tft.setTextSize(2);
  tft.print(F("Hor/Ve Lines   "));
  tft.setTextColor(TFT_YELLOW);
  tft.setTextSize(2);
  printnice(usecFastLines);

  tft.setTextColor(TFT_CYAN);
  tft.setTextSize(2);
  tft.print(F("Rectangles     "));
  tft.setTextColor(TFT_YELLOW);
  tft.setTextSize(2);
  printnice(usecRects);
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

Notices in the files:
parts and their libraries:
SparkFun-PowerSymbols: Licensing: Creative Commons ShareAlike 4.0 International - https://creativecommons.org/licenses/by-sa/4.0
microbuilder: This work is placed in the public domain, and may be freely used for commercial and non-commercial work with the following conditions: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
